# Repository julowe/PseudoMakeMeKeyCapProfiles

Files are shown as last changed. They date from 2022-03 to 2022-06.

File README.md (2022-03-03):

# Pseudo Make Me Key Cap Profile

## How to
* make sure OpenSCAD is up to date.
* unzip libraries.zip into your OpenSCAD libraries
  * if using OpenSCAD 2019.5 (or above, likely), comment out line 7 (`function is_undef(x) = len(x) > 0 ? vec_is_undef(x) : x == undef;`) from `tracjectory.scad` from `libraries.zip`. This removes a compilation warning message.
* select keycap you want to render by changing KeyID value
* change KeyID to corresponding Parameter ID
* press F5 to review
* press F6 to render
* press F7 to export as STL

## STL Files
STLs for some keycaps are stored in the `STL` directory. Filenames include some parameter values that are outside of the 'defined' keycap calling function assoicated with the keycap name.

## TODO - Known Errors
* Chicago Steno R2/R4 1.5u renders with no stems
* Chicago Steno R3 1.5u renders with no dish on top of keycap

## Distorted Ellipsoidal Saddle (DES)
High sculpt smooth transition profile
DES
### Standard
Neuron v1

### Concave
Corne thumb and Convex Caps

### Thumbs
IMK Corne v1
Kyria

### Chicago Stenographer
Subtly sculpted choc spaced low profile
CS
#### Standard
Look

#### Convex
Georgi
#### Thumbs
1.5 + 1
Additional sculpt angle and smoother transitions

### Philadelphia Minimalist
under
Minimal spacing
Under construction

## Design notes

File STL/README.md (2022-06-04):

# What are these STLs?

ccs if for Choc Chicago Steno

then r3 etc means row 3 profile

then various parameters used in scad file to create STLs

Changes from previously posted versions are modification to the stem (which goes into keyswitch). When looking at keycap from top down (or bottom up) I made the portion of the stem that intersects the X-Y plane wider along the X axis (the shorter dimension of this scalloped rectangle) and the Y axis shorter. I did this because I had to shave off some plastic on all the stemsm and it was also a loose fit side to side. Your mileage may vary with printer settings etc, so do a test print! Don't print a bunch and then get fed up and reprint them like I did.

## Printing Suggestions

I prefer printing the keycaps vertically - see screengrabs from Prusa below. One showing print orientation and generated supports, and one showing the selective support enforcer cubes I added so that Prusa didn't go crazy with supports everywhere.

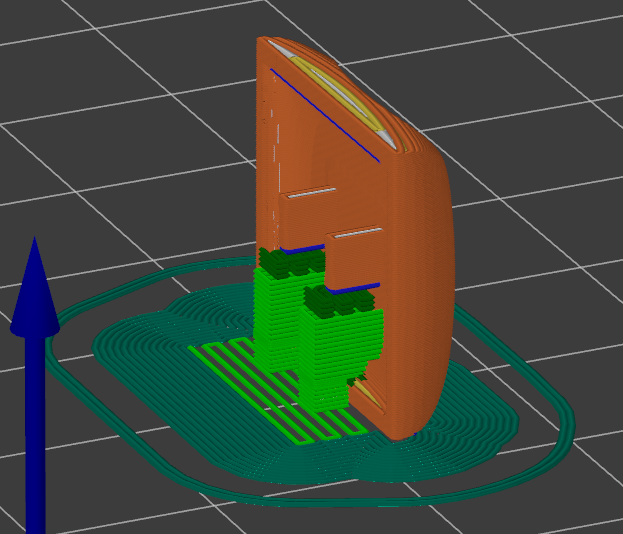
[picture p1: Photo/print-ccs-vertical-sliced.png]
Print Orientation and Generated Supports


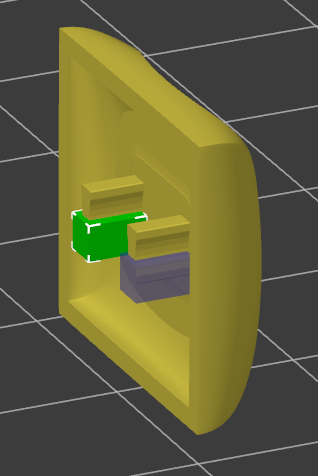
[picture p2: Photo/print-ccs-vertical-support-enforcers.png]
Support Enforcers


Why did I bother with this? Becuse if you print them such that the stems are flat against the build plate (so that the main surface of the keycap which you touch is parallel with build plate) you get layer lines on exactly that main part of the keycap you touch. They aren't horrible, and if you go thin enough you can't really feel them. It's more a confusing texture than bumpy/ridged, but I'm customizing scad files to creat custom keycaps for a custom board - of course I did one more hting to make my life harder. Printing vertically makes the keycaps much smoother at a quicker/larger layer height. The other big reason I printed them vertically is I could then use rainbow filament to print the keycaps and get a neat gradient.

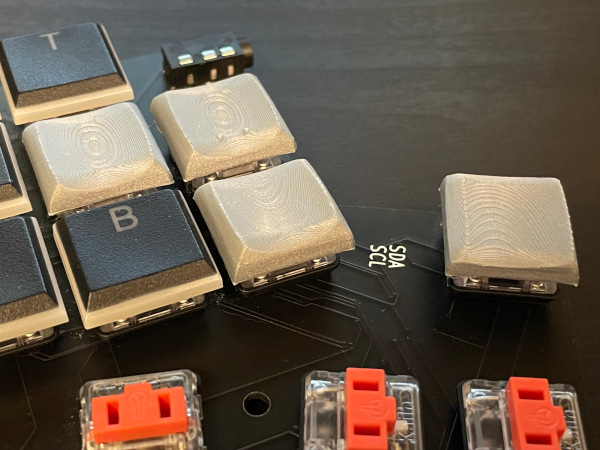
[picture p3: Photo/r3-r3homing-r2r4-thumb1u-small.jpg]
Outcome of printing keycaps flat, instead of vertically


Rainbow gradient on vertically printed keycaps

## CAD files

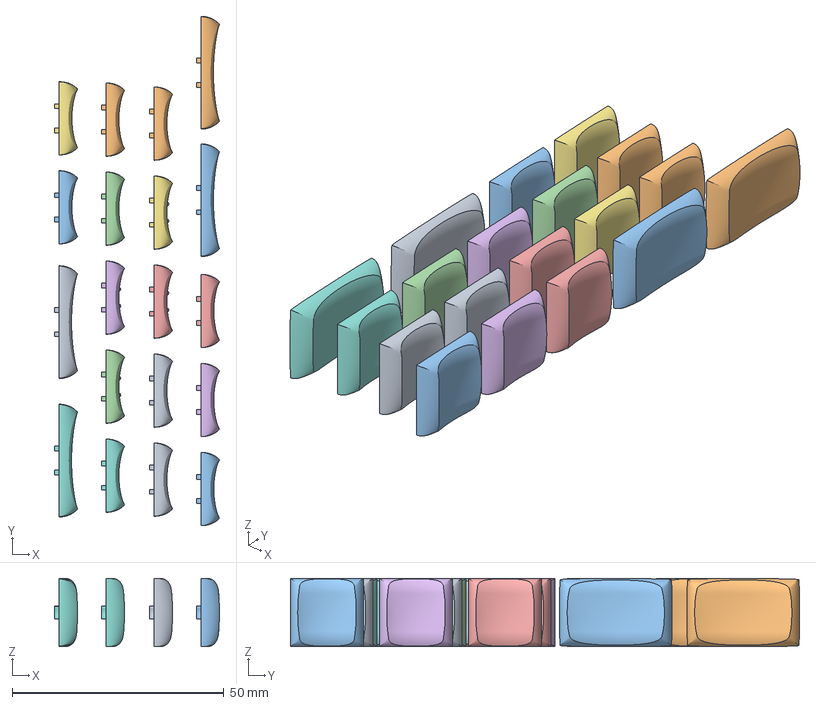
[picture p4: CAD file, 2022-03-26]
STL/row3.3mf
38.9 x 120.2 x 16.1 mm
ccs-r3-flat-stemLength2.8-stemWidth1.3-wall1.1-top2.5-stepsize50-step2-fn90-layers50.stl
ccs-r3-flat-homing-stemLength2.8-stemWidth1.3-wall1.1-top2.5-stepsize50-step2-fn90-layers50.stl
ccs-r3-1.5u-flat-stemLength2.8-stemWidth1.3-wall1.1-top2.5-stepsize50-step2-fn90-layers50.stl

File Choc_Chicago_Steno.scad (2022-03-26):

use <scad-utils/morphology.scad> //for cheaper minwoski 
use <scad-utils/transformations.scad>
use <scad-utils/shapes.scad>
use <scad-utils/trajectory.scad>
use <scad-utils/trajectory_path.scad>
use <sweep.scad>
use <skin.scad> 
//use <z-butt.scad> 

//Choc Chord version Chicago Stenographer

/*Tester */
//keycap(
//  keyID  = 1, //change profile refer to KeyParameters Struct
//  cutLen = 0, //Don't change. for chopped caps
//  Stem   = true, //turn on shell and stems
//  StemRot = 0, //change stem orientation by deg
//  Dish   = true, //turn on dish cut
//  Stab   = 0,
//  visualizeDish = false, // turn on debug visual of Dish
//  crossSection  = false, // center cut to check internal
//  homeDot = false, //turn on homedots
//  Legends = false
//);

/* Requested Keys */

// REMEMBER zero-indexed

////Chicago Steno R2/R4
//keycap(
//  keyID  = 0, //change profile refer to KeyParameters Struct
//  cutLen = 0, //Don't change. for chopped caps
//  Stem   = true, //turn on shell and stems
//  StemRot = 0, //change stem orientation by deg
//  Dish   = true, //turn on dish cut
//  Stab   = 0,
//  visualizeDish = false, // turn on debug visual of Dish
//  crossSection  = false, // center cut to check internal
//  homeDot = false, //turn on homedots
//  Legends = false
//);
 
////Chicago Steno R3 flat
//keycap(
//  keyID  = 1, //change profile refer to KeyParameters Struct
//  cutLen = 0, //Don't change. for chopped caps
//  Stem   = true, //turn on shell and stems
//  StemRot = 0, //change stem orientation by deg
//  Dish   = true, //turn on dish cut
//  Stab   = 0,
//  visualizeDish = false, // turn on debug visual of Dish
//  crossSection  = false, // center cut to check internal
//  homeDot = false, //turn on homedots
//  Legends = false
//);
  
////Chicago Steno R3 flat Homing Dots
//keycap(
//  keyID  = 1, //change profile refer to KeyParameters Struct
//  cutLen = 0, //Don't change. for chopped caps
//  Stem   = true, //turn on shell and stems
//  StemRot = 0, //change stem orientation by deg
//  Dish   = true, //turn on dish cut
//  Stab   = 0,
//  visualizeDish = false, // turn on debug visual of Dish
//  crossSection  = false, // center cut to check internal
//  homeDot = true, //turn on homedots
//  Legends = false
//);
  
////Chicago Steno R2/R4 1.5
//keycap(
//  keyID  = 7, //change profile refer to KeyParameters Struct
//  cutLen = 0, //Don't change. for chopped caps
//  Stem   = true, //turn on shell and stems
//  StemRot = 0, //change stem orientation by deg
//  Dish   = true, //turn on dish cut
//  Stab   = 0,
//  visualizeDish = false, // turn on debug visual of Dish
//  crossSection  = false, // center cut to check internal
//  homeDot = false, //turn on homedots
//  Legends = false
//  /* ERROR FIXME - no stems, but has dish
//  ERROR: CGAL error in CGALUtils::applyBinaryOperator union: CGAL ERROR: assertion violation! Expr: itl != it->second.end() File: /usr/include/CGAL/Nef_3/SNC_external_structure.h Line: 1144
//  */
//);
  
//Chicago Steno R3 1.5u
keycap(
  keyID  = 8, //change profile refer to KeyParameters Struct
  cutLen = 0, //Don't change. for chopped caps
  Stem   = true, //turn on shell and stems
  StemRot = 0, //change stem orientation by deg
  Dish   = true, //turn on dish cut
  Stab   = 0,
  visualizeDish = false, // turn on debug visual of Dish
  crossSection  = false, // center cut to check internal
  homeDot = false, //turn on homedots
  Legends = false
  /* ERROR FIXME - has stems but no dish
  ERROR: CGAL error in CGAL_Nef_polyhedron3(): CGAL ERROR: assertion violation! Expr: ss_circle.has_on(sv_prev->point()) File: /usr/include/CGAL/Nef_3/polygon_mesh_to_nef_3.h Line: 256
  ERROR: CGAL error in CGAL_Nef_polyhedron3(): CGAL ERROR: assertion violation! Expr: ss_circle.has_on(sv_prev->point()) File: /usr/include/CGAL/Nef_3/polygon_mesh_to_nef_3.h Line: 256

TODO try iterating through parameters from 1u, start with height?
  */
);

/* Map of KeyIDs to Comment Name
easierToReadListOfkeyParameters = //keyParameters[KeyID][ParameterID]
[
    //Column 0
    //Levee: Chicago in choc Dimension
    0[], //Chicago Steno R2/R4
    1[], //Chicago Steno R3 flat
    2[], //Chicago Steno R3 chord
    //mods 3
    
    3[], //Levee Corner R2
    4[], //Levee Corner R2
    //1.25 5
    5[], //Chicago Steno R2/R4 1.25u
    6[], //Chicago Steno R3 1.25u
    //1.5 7
    7[], //Chicago Steno R2/R4 1.5u
    8[], //Chicago Steno R3 1.5u
    //1.75 9
    9[], //Chicago Steno R2/R4 1.75u
    10[], //Chicago Steno R3 1.75u
    //2.00 11
    11[], //Chicago Steno R2/R4 2.0u
    12[], //Chicago Steno R3 2.0u
    // Ergo shits
    13[], //highpro 19.05 R2|4
    14[], //Chicago Steno R2 ALT
    15[], //Chicago Steno R1 Steap
    16[] //Chicago Steno R1 mild with alt R2
];
 END Map of KeyIDs to Comment Name */
 //end


//-Parameters
wallthickness = 1.1; // 1.75 for mx size, 1.1
topthickness = 2.5; //2 for phat 3 for chicago
stepsize = 50;  //resolution of Trajectory
step = 2;       //resolution of ellipes 
//fn = 18;          //resolution of Rounded Rectangles: 18 for preview
fn = 90;          //resolution of Rounded Rectangles: 90 for export
layers = 50;    //resolution of vertical Sweep: 50 for output


//this means the slope form keycap underside to what goes into key switches...
//---Stem param
slop    = 0.3;
stemRot = 0;
stemWid = 8;
stemLen = 6;
stemCrossHeight = 1.8;
extra_vertical = 0.6;
stemLayers = 50; //resolution of stem to cap top transition
//#cube([18.16, 18.16, 10], center = true); // sanity check border

//injection param
draftAngle = 0; //degree  note:Stem Only
//TODO: Add wall thickness transition?
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

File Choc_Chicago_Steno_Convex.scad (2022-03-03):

use <scad-utils/morphology.scad> //for cheaper minwoski 
use <scad-utils/transformations.scad>
use <scad-utils/shapes.scad>
use <scad-utils/trajectory.scad>
use <scad-utils/trajectory_path.scad>
use <sweep.scad>
use <skin.scad>  
//use <z-butt.scad>

//NOTE: with sweep cuts, top surface may not be visible in review, it should be visible once rendered

Legends = false; //not coded as a passed param to funtction, but still used, so just made it a lazy global
mirror([0,0,0])keycap(
  keyID  = 0, //change profile refer to KeyParameters Struct
  cutLen = 0, //Don't change. for chopped caps
  Stem   = true, //turn on shell and stems
  StemRot = 0,//change stem orientation by deg
  Dish   = true, //turn on dish cut
  Stab   = 0, 
  visualizeDish = false, // turn on debug visual of Dish 
  crossSection  = false, // center cut to check internal
  homeDot = false //turn on homedots
  /* ERROR FIXME - renders without stems
  PolySet has nonplanar faces. Attempting alternate construction
  ERROR: CGAL error in CGALUtils::applyBinaryOperator union: CGAL ERROR: assertion violation! Expr: itl != it->second.end() File: /usr/include/CGAL/Nef_3/SNC_external_structure.h Line: 1144
  */
); 

//Parameters
wallthickness = 1.2;   
topthickness  = 2;   //
stepsize      = 50;  //resolution of Trajectory
step          = 1;   //resolution of ellipes 
fn            = 18;  //resolution of Rounded Rectangles: 18 for preview
fn            = 90;  //resolution of Rounded Rectangles: 90 for export
layers        = 40;  //resolution of vertical Sweep: 50 for output
dotRadius     = 1.25;   //home dot size
//---Stem param
slop    = 0.25;
stemWid = 8;
stemLen = 6;
stemCrossHeight = 1.8;
extra_vertical  = 0.6;
StemBrimDep     = 0; 
stemLayers      = 50; //resolution of stem to cap top transition
driftAngle      = 0;

keyParameters = //keyParameters[KeyID][ParameterID]
[
//  BotWid, BotLen, TWDif, TLDif, keyh, WSft, LSft  XSkew, YSkew, ZSkew, WEx, LEx, CapR0i, CapR0f, CapR1i, CapR1f, CapREx, StemEx
    //Column 0    
    //Levee: Chicago in choc Dimension 
    [17.20,  16.00,   5.6, 	   5,  3.8,    0,  -.5,     7,    -0,    -0,   2, 2,    .10,      3,     .10,      3,     2,       2], //Chicago Steno R2x 1u
    [17.20,  16.00,   5.6, 	   5,  4.4,    0,   .0,     0,    -0,    -0,   2, 2,    .10,      3,     .10,      3,     2,       2], //Chicago Steno R3x 1u
    [35.85,  15.65,     7, 	   7,  4.4,    0,   .0,     0,    -0,    -0,   2, 2,    .30,      5,     .30,      5,     2,       2], //Chicago Steno R3x 1.5u 
    [35.85,  15.65,     7, 	   7,  4.4,    0,   .0,     0,    -0,    -0,   2, 2,    .30,      5,     .30,      5,     2,       2], //Chicago Steno R3x 2u 
    //mods 3
    
    [17.20,  16.00,  4.25, 	3.25,  5.5,  -.7,  0.7,     0,    -4,    -0,   2,   2,    .10,      2,     .10,      2,     2,       2], //Levee Corner R2
    [17.20,  16.00,  4.25, 	3.25,  5.2,  -.8,  0.6,     0,    -4,    -0,   2,   3,    .10,      2,     .10,      2,     2,       2], //Levee Corner R2
    //1.25 5
    [21.3,   15.60,  5.6, 	   5,  4.5,    0,   .0,     5,    -0,    -0,   2,   2,     .5,      3,      .5,      3,     2,       2], //Chicago Steno R2/R4 1.25u
    [21.4,   15.60,  5.6, 	   5,  4.5,    0,   .0,     0,    -0,    -0,   2,   2,     .5,      3,      .5,      3,     2,       2], //Chicago Steno R3 1.25u
    //1.5 7
    [26.15,  15.60,   5.6, 	   5,  4.5,    0,   .0,     5,    -0,    -0,   2,   2,     .5,      3,      .5,      3,     2,       2], //Chicago Steno R2/R4 1.5
    [26.15,  15.60,   5.6, 	   5,  4.5,    0,   .0,     0,    -0,    -0,   2,   2,     .5,      3,      .5,      3,     2,       2], //Chicago Steno R3 1.5u
    //1.75 9
    [30.90,  15.60,   5.6, 	   5,  4.5,    0,   .0,     5,    -0,    -0,   2,   2,     .5,      3,      .5,      3,     2,       2], //Chicago Steno R2/R4 1.5
    [30.90,  15.60,   5.6, 	   5,  4.5,    0,   .0,     0,    -0,    -0,   2,   2,     .5,      3,      .5,      3,     2,       2], //Chicago Steno R3 1.5u
    // Ergo shits
    [18.75,  18.75,   5.6, 	   5,    8,    0,   .25,     0,    -0,    -0,   2, 2.5,    .10,      3,     .10,      3,     2,       2], //highpro 19.05 R2|4 
    [17.20,  16.00,   5.6, 	   5,  4.7,    0,   .0,      3,    -0,    -0,   2, 2.5,    .10,      2,     .10,      3,     2,       2], //Chicago Steno R2 ALT
    [17.20,  16.00,   5.6, 	   5,  5.5,    0,   .0,      7,    -0,    -0,   2, 2.5,    .10,      2,     .10,      3,     2,       2], //Chicago Steno R1 Steap
    [17.20,  16.00,   5.6, 	   5,  7.0,    0,   .0,     10,    -0,    -0,   2, 2.5,    .10,      2,     .10,      3,     2,       2], //Chicago Steno R1 mild with alt R2
];

dishParameters = //dishParameter[keyID][ParameterID]
[ 
//FFwd1 FFwd2 FPit1 FPit2  DshDepi DishDepf,DshHDif FArcIn FArcFn FArcEx     BFwd1 BFwd2 BPit1 BPit2  BArcIn BArcFn BArcEx
  [   5,  2.3,    2,  -55,    1.5,   3.75,   8.5,    8.5,    2,       5,    3,    2,  -50,    8.5,    8.7 ,     2], //R2x 1u
  [ 4.5,  3.3,   -3,  -45,    1.5,   3.75,   8.5,   8.7,     2,     4.5,  3.3,   -3,  -45,    8.5,   8.7,     2], //R3x 1u
  [ 4.5,  3.2,   -5,  -45,    1.5,   3.75,  19.0,    18,     2,     4.5,  3.2,   -5,  -45,   19.0,    18,     2], //R3x 2u
  [ 4.5,  3.2,   -5,  -45,    1.5,   3.75,  19.0,    18,     2,     4.5,  3.2,   -5,  -45,   19.0,    18,     2], //R3x 2u
  [   4,  4.2,   -5,  -15,      1,      3,  18.2,    21,     2,       5,    3,   -5,  -15,   18.2,    21,     2], //R3 2u
  [  4.,  1.5,    8,  -55,      3,      7,   9.0,     9,     2,       4,    3,    3,  -50,    9,     9,     2],  //R3
  [  4.,  1.5,   -0,  -50,      3,      7,   9.0,     9,     2,       4,    3,    -10,  -50,    9,     9,     2],  //R3
  [   5,  3.5,    8,  -50,      5,    1.8,   8.8,    15,     2,       6,    4,   13,   30,    8.8,    16,     2], //R1
];
 
function FrontForward1(keyID) = dishParameters[keyID][0];  //
function FrontForward2(keyID) = dishParameters[keyID][1];  // 
function FrontPitch1(keyID)   = dishParameters[keyID][2];  //
function FrontPitch2(keyID)   = dishParameters[keyID][3];  //
function DishDepth(keyID)     = dishParameters[keyID][4];  //
function DishHeightDif(keyID) = dishParameters[keyID][5];  //
function FrontInitArc(keyID)  = dishParameters[keyID][6];
function FrontFinArc(keyID)   = dishParameters[keyID][7];
function FrontArcExpo(keyID)  = dishParameters[keyID][8];
function BackForward1(keyID)  = dishParameters[keyID][9];  //
function BackForward2(keyID)  = dishParameters[keyID][10];  // 
function BackPitch1(keyID)    = dishParameters[keyID][11];  //
function BackPitch2(keyID)    = dishParameters[keyID][12];  //
function BackInitArc(keyID)   = dishParameters[keyID][13];
function BackFinArc(keyID)    = dishParameters[keyID][14];
function BackArcExpo(keyID)   = dishParameters[keyID][15];

function BottomWidth(keyID)  = keyParameters[keyID][0];  //
function BottomLength(keyID) = keyParameters[keyID][1];  // 
function TopWidthDiff(keyID) = keyParameters[keyID][2];  //
function TopLenDiff(keyID)   = keyParameters[keyID][3];  //
function KeyHeight(keyID)    = keyParameters[keyID][4];  //
function TopWidShift(keyID)  = keyParameters[keyID][5];
function TopLenShift(keyID)  = keyParameters[keyID][6];
function XAngleSkew(keyID)   = keyParameters[keyID][7];
function YAngleSkew(keyID)   = keyParameters[keyID][8];
function ZAngleSkew(keyID)   = keyParameters[keyID][9];
function WidExponent(keyID)  = keyParameters[keyID][10];
function LenExponent(keyID)  = keyParameters[keyID][11];
function CapRound0i(keyID)   = keyParameters[keyID][12];
function CapRound0f(keyID)   = keyParameters[keyID][13];
function CapRound1i(keyID)   = keyParameters[keyID][14];
function CapRound1f(keyID)   = keyParameters[keyID][15];
function ChamExponent(keyID) = keyParameters[keyID][16];
function StemExponent(keyID) = keyParameters[keyID][17];

function FrontTrajectory(keyID) = 
  [
    trajectory(forward = FrontForward1(keyID), pitch =  FrontPitch1(keyID)), //more param available: yaw, roll, scale
    trajectory(forward = FrontForward2(keyID), pitch =  FrontPitch2(keyID))  //You can add more traj if you wish 
  ];

function BackTrajectory (keyID) = 
  [
    trajectory(forward = BackForward1(keyID), pitch =  BackPitch1(keyID)),
    trajectory(forward = BackForward2(keyID), pitch =  BackPitch2(keyID)),
  ];

//------- function defining Dish Shapes

function ellipse(a, b, d = 0, rot1 = 0, rot2 = 360) = [for (t = [rot1:step:rot2]) [a*cos(t)+a, b*sin(t)*(1+d*cos(t))]]; //Centered at a apex to avoid inverted face

function DishShape (a,b,c,d) = 
  concat(
   [[c+a,-b]],
    ellipse(a, b, d = 0,rot1 = 270, rot2 =450),
   [[c+a,b]]
  );

function oval_path(theta, phi, a, b, c, deform = 0) = [
 a*cos(theta)*cos(phi), //x
 c*sin(theta)*(1+deform*cos(theta)) , // 
 b*sin(phi),
]; 
  
path_trans2 = [for (t=[0:step:180])   translation(oval_path(t,0,10,15,2,0))*rotation([0,90,0])];
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

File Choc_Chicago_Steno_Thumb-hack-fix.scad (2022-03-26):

use <scad-utils/morphology.scad> //for cheaper minwoski 
use <scad-utils/transformations.scad>
use <scad-utils/shapes.scad>
use <scad-utils/trajectory.scad>
use <scad-utils/trajectory_path.scad>
use <sweep.scad>
use <skin.scad>  
//use <z-butt.scad>
// Choc Chord version Chicago Stenographer with sculpte Thumb cluter
// change stemrot 


//mirror([1,0,0]) {
keycap(
  keyID   = 4, //change profile refer to KeyParameters Struct
  cutLen  = 0, //Don't change. for chopped caps
  Stem    = true, //turn on shell and stems
  StemRot = 90,//change stem orientation by deg
  Dish    = true, //turn on dish cut
  Stab    = 0, 
  visualizeDish = false, // turn on debug visual of Dish 
  crossSection  = false, // center cut to check internal
  homeDot = false, //turn on homedots
  Legends = false
); 
//}

/* Map of KeyIDs to Comment Name

easierToReadListOfkeyParameters = //keyParameters[KeyID][ParameterID]
[
    //Column 0    
    //Levee: Chicago in choc Dimension for ref 
    0[], //Levee Steno R2/R4 
    1[], //Levee Steno R3
    //Thumb
    2[], //Thumb 1
    3[], //Thumb 1.5
    4[], //Thumb 2.0
    //1.25 5
    5[], //Chicago Steno R2/R4 1.25u
    6[], //Chicago Steno R3 1.25u
    //1.5 7
    7[], //Chicago Steno R2/R4 1.5
    8[], //Chicago Steno R3 1.5u
    //1.75 9
    9[], //Chicago Steno R2/R4 1.5
    10[], //Chicago Steno R3 1.5u
    // Ergo shits
    11[], //highpro 19.05 R2|4 
    12[], //Chicago Steno R2 ALT
    13[], //Chicago Steno R1 Steap
    14[], //Chicago Steno R1 mild with alt R2

];
END Map of KeyIDs to Comment Name */
//end

//-Parameters
wallthickness = 1.1; // 1.75 for mx size, 1.1
topthickness = 2.5; //2 for phat 3 for chicago
stepsize = 40;  //resolution of Trajectory
step =2;       //resolution of ellipes 
//fn = 18;          //resolution of Rounded Rectangles: 18 for preview
fn = 90;          //resolution of Rounded Rectangles: 90 for export
layers = 50;    //resolution of vertical Sweep: 50 for output

//---Stem param
slop    = 0.3;
//stemWid = 8;
//stemLen = 6;

//swapped x&y for rot 90 deg
//line 337 buggery too
stemWid = 6;
stemLen = 8;
stemCrossHeight = 1.0; //1.8 default
extra_vertical = 4.6;
stemLayers = 50; //resolution of stem to cap top transition 50 default
//#cube([18.16, 18.16, 10], center = true); // sanity check border

//injection param
draftAngle = 0; //degree  note:Stem Only
//TODO: Add wall thickness transition?

keyParameters = //keyParameters[KeyID][ParameterID]
[
//  BotWid, BotLen, TWDif, TLDif, keyh, WSft, LSft  XSkew, YSkew, ZSkew, WEx, LEx, CapR0i, CapR0f, CapR1i, CapR1f, CapREx, StemEx
    //Column 0    
    //Levee: Chicago in choc Dimension for ref 
    [17.20,  16.00,   5.6, 	   5,  5.0,    0,   .0,     5,    -0,    -0,   2, 2.5,    .10,      2,     .10,      3,     2,       2], //Levee Steno R2/R4 
    [17.20,  16.00,   5.6, 	   5,  4.6,    0,   .0,     0,    -0,    -0,   2, 2.5,    .10,      3,     .10,      3,     2,       2], //Levee Steno R3
    //Thumb
    [17.20,  16.00,  4.25, 	3.25,  5.0,  -.5,  0.0,    -3,    -3,    -0,   2,   2,    .10,      2,     .10,      2,     2,       2], //Thumb 1
    [15.65,  26.4,   5.5, 	3.25,  4.9,  -.5,  0.0,    -3,    -2,    -2,   2,   2,     .3,      2,      .3,    2.5,     2,       2], //Thumb 1.5
    [15.65,  35.8,  4.25, 	3.25,  4.9, -.25,  0.0,    -2.5,    -4,    -2,   2,   3,     .3,      2,      .3,    2.5,     2,       2], //Thumb 2.0
    //1.25 5
    [21.3,   15.60,  5.6, 	   5,  4.5,    0,   .0,     5,    -0,    -0,   2,   2,     .5,      3,      .5,      3,     2,       2], //Chicago Steno R2/R4 1.25u
    [21.4,   15.60,  5.6, 	   5,  4.5,    0,   .0,     0,    -0,    -0,   2,   2,     .5,      3,      .5,      3,     2,       2], //Chicago Steno R3 1.25u
    //1.5 7
    [26.15,  15.60,   5.6, 	   5,  4.5,    0,   .0,     5,    -0,    -0,   2,   2,     .5,      3,      .5,      3,     2,       2], //Chicago Steno R2/R4 1.5
    [26.15,  15.60,   5.6, 	   5,  4.5,    0,   .0,     0,    -0,    -0,   2,   2,     .5,      3,      .5,      3,     2,       2], //Chicago Steno R3 1.5u
    //1.75 9
    [30.90,  15.60,   5.6, 	   5,  4.5,    0,   .0,     5,    -0,    -0,   2,   2,     .5,      3,      .5,      3,     2,       2], //Chicago Steno R2/R4 1.5
    [30.90,  15.60,   5.6, 	   5,  4.5,    0,   .0,     0,    -0,    -0,   2,   2,     .5,      3,      .5,      3,     2,       2], //Chicago Steno R3 1.5u
    // Ergo shits
    [18.75,  18.75,   5.6, 	   5,    8,    0,   .25,     0,    -0,    -0,   2, 2.5,    .10,      3,     .10,      3,     2,       2], //highpro 19.05 R2|4 
    [17.20,  16.00,   5.6, 	   5,  4.7,    0,   .0,      3,    -0,    -0,   2, 2.5,    .10,      2,     .10,      3,     2,       2], //Chicago Steno R2 ALT
    [17.20,  16.00,   5.6, 	   5,  5.5,    0,   .0,      7,    -0,    -0,   2, 2.5,    .10,      2,     .10,      3,     2,       2], //Chicago Steno R1 Steap
    [17.20,  16.00,   5.6, 	   5,  7.0,    0,   .0,     10,    -0,    -0,   2, 2.5,    .10,      2,     .10,      3,     2,       2], //Chicago Steno R1 mild with alt R2

];

dishParameters = //dishParameter[keyID][ParameterID]
[ 
//FFwd1 FFwd2 FPit1 FPit2  DshDep DshHDif FArcIn FArcFn FArcEx     BFwd1 BFwd2 BPit1 BPit2  BArcIn BArcFn BArcEx FTani FTanf BTani BTanf TanEX PhiInit PhiFin
  //Column 0
  [ 4.5,    4,    7,  -50,      7,    1.7,   11,    17,     2,      4.5,    4,    2,   -35,   11,    15,     2,     3,  4.5,    3,  4.5,   2, 203, 210], //Chicago Steno R2/R4
  [ 4.5,    4,    5,  -40,      7,    1.7,   11,    15,     2,      4.5,    4,    5,   -40,   11,    15,     2,     4,    5,    4,    5,   2, 200, 210], //Chicago Steno R3 flat
  
  [   5,  5.5,    0,  -40,      7,    1.7,   16,    18,     2,       5.5,  3.5,    5,   -50,   16,    18,     2,     5,   3.75,    2,    3.75,   2, 199, 210], //T1
  [  10,  4.5,    0,  -40,      7,    1.7,   16,    15,     2,        10,  3.5,    5,   -50,   16,    18,     2,     3,   3.75,    .75,    3.75,   2, 200, 210], //1.5u 
  [  14.5, 4.5,   4,  -40,      7,    1.7,   16,    18,     2,      14.5,  4.5,    2,   -35,   16,    23,     2,     3,   3.75,    .75,    3.75,   2, 200, 210], //2.0u 
  //1.25
  [ 4.5,    4,    7,  -40,      8,    1.8,   15,    20,     2,      4.5,    4,    2,   -35,   15,    20,     2,     3,    5,    7,    5,   2, 200, 210], //Chicago Steno R2/R4
  [ 4.5,    4,    5,  -40,      8,    1.8,   15,    20,     2,      4.5,    4,    5,   -40,   15,    20,     2,     3,    5,    7,    5,   2, 200, 210], //Chicago Steno R3
  //1.5
  [ 4.5,    4,    7,  -40,      8,    1.8,   19,    25,     2,      4.5,    4,    2,   -35,   19,    25,     2], //Chicago Steno R2/R4
  [ 4.5,    4,    5,  -40,      8,    1.8,   19,    25,     2,      4.5,    4,    5,   -40,   19,    25,     2], //Chicago Steno R3
  //1.75
  [ 4.5,    4,    7,  -40,      8,    1.8,   22.5,  27,     2,      4.5,    4,    2,   -35,   22.5,  27,     2], //Chicago Steno R2/R4
  [ 4.5,    4,    5,  -40,      8,    1.8,   22.5,  27,     2,      4.5,    4,    5,   -40,   22.5,  27,     2], //Chicago Steno R3
  
  
  [   5,    5,    5,  -40,      7,    1.7,   11,    15,     2,        5,    5,    5,   -40,   11,    15,     2], //Chicago Steno R3 flat
  [ 4.5,    4,    7,  -50,      7,    1.7,   11,    17,     2,      4.5,    4,    2,   -35,   11,    15,     2], //Chicago Steno R1
  [ 4.5,    4,    7,  -50,      7,    1.7,   11,    17,     2,      4.5,    4,    2,   -35,   11,    15,     2], //Chicago Steno R1
  [ 4.5,    4,    7,  -50,      7,    1.7,   11,    17,     2,      4.5,    4,    2,   -35,   11,    15,     2], //Chicago Steno R1

];
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

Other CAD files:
Choc_Chicago_Steno_Thumb.scad

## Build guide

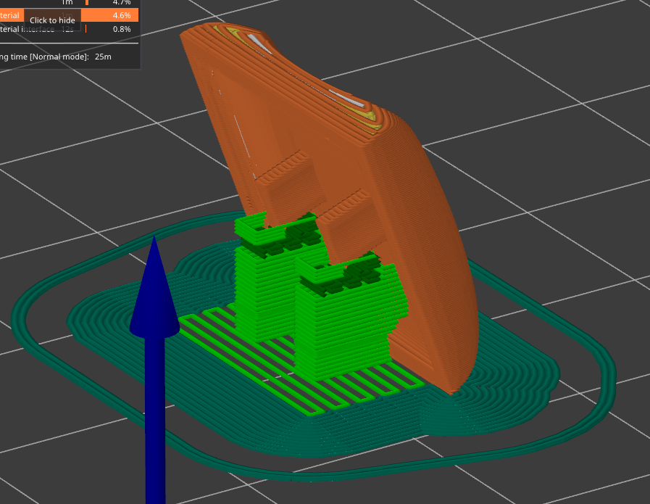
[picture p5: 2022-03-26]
Photo/print-ccs-30deg-sliced.png

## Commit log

2022-03-03 add note on STL files
2022-03-03 Add specific keycap helper/test functions
    [Choc_Chicago_Steno.scad, Choc_Chicago_Steno_Thumb.scad]
2022-03-03 add STL files for some choc chicago steno keycaps
2022-03-03 Fixed stem rotation bug, changes to params in tester/render function
    [Choc_Chicago_Steno_Thumb.scad]
2022-03-03 r2x 1u does not render with stems. errors in comment
    [Choc_Chicago_Steno_Convex.scad]
2022-03-05 A worse but functional fix for stem rotation on 2u thumb
    Previous 'fix' rotated skin under keycap dish, but was actually seperated from material so not printable. This just removes the skin completely so only the stems are still there
    [Choc_Chicago_Steno_Thumb.scad]
2022-03-05 STL of 2u thumb with only stems, no under-bevel from skin() function
2022-03-06 add image of some printed keycaps
2022-03-26 removing STL files that weren't great
2022-03-26 Changed keyParameters and made values into variables
    changed keyParameters for steno r2/r4 1.5u as it didn't look to be set right, set homeDotBumpUp as variable in function vs hardcoded, Stem module has more values as named variables now, not passable tho.
    [Choc_Chicago_Steno.scad]
2022-03-26 ugly hack to made printable thumb 2u key
    extended stems up into keycap body and then removed sloped connection point and just put a cube there. not great but works
    [Choc_Chicago_Steno_Thumb.scad]
2022-03-26 another iteration of hacks to make printable thumb 2u keycap
    this one throws some magic numbers around and makes the sloped connection between keycap underside and stems a bit thicker by decreasing stemCrossHeight and adding to Z value in stemTranslation funct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
    [Choc_Chicago_Steno_Thumb-hack-fix.scad]
2022-03-26 Add photos of printing orientation and selective supports
2022-03-26 STLs for gergo row 3
    [row3.3mf]
2022-03-26 revert (mostly) to upstream Thumb.scad version
    [Choc_Chicago_Steno_Thumb.scad]
2022-03-26 values to variables
    converted some values in choc_stem() & Stem() into named variables for easier iteration of values. useful for fine tuning to specific printer capabilities/quirks. any changed values also have the ori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
    [Choc_Chicago_Steno_Thumb.scad]
2022-03-26 moved stab creation outside rotation code. might work better? untested in any way. stab actually gets created in middle of keycap with or without this change
    [Choc_Chicago_Steno_Thumb-hack-fix.scad]
2022-06-04 add STL readme to explain file naming and some reasoning for choices
2022-06-04 move jpg from STL dir to Photo dir
2022-06-04 add photos to readme of prusa orientation and printed keycaps
